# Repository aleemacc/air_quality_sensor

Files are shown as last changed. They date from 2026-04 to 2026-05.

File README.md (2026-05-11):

# Description
This project consists on the full development of an embedded system, with the purpose of measuring air quality.
### Included in this project:
- PCB design and schematics
- Firmware for the device
- Communication with other devices
- Integration with external systems (graphical interface)

# Characteristics
- The device will be able to measure the following:
  - Temperature
  - Humidity
  - CO2 levels
  - TVOC
  - NOx
  - LPG
  - CO
- Wireless connectivity (WiFi, BLE or LoRa)
- Modularity. Ideally you should be able to use only the sensors you need.

# Hardware
## ESP32-C6
The device is built around Seed Studio's ESP32-C6 dev-board, this simplifies the PCB design. Given its size and extensive set of features, it gives the project tons of flexibility.

## Sensors
### SCD41
Sensirion's SCD41 provides temperature, humidity and CO2 measurements with enough precision for home use. It also includes calibration for the CO2 measurements.
### SGP41
Also from Sensirion, but it measures TVOC and NOx. Temperature from the previous sensor can be used to calibrate the SGP41.
### MQ-6
Manufactured by SparkFun, this is a LPG sensor.
### MQ-7
Once again manufactured by SparkFun, this senses Carbon Monoxide.

## Display
The design features a FFC connector to add a TFT display.

## Power
When powered by the ESP's USB-C connector, the ESP board itself provides power to every component.
When a one cell battery pack is used (ie. 18650 or 18300 Li-ion), components powered by 3V3 are still managed by the ESP. However, sensors requiring 5V are powered through a Boost Converter that transforms the batteries voltage to a steady 5V.

## Interfaces
The sensor SCD41 and SGP41 communicate over I2C, both MQ-x sensors use an analog signal and the display will be set up to use 4-wire SPI.

# PCB
The current version of the project features a 2 layer PCB, with the bottom one being a ground plane.
The large space in the middle is there to give space for a 18650 or 18300 battery (depending on which sensors are installed). It also serves to distance the SCD41 sensor from heat sources, such as the MCU or the boost converter.
The SCD41 sensor is excluded from the ground plane and placed within an isolation island, for better accuracy in the temperature measurements

# Firmware
This device is intended to work both with home assistant and independently.
For now only yaml code has been added for testing in home assistant with limited functionality.

# Images

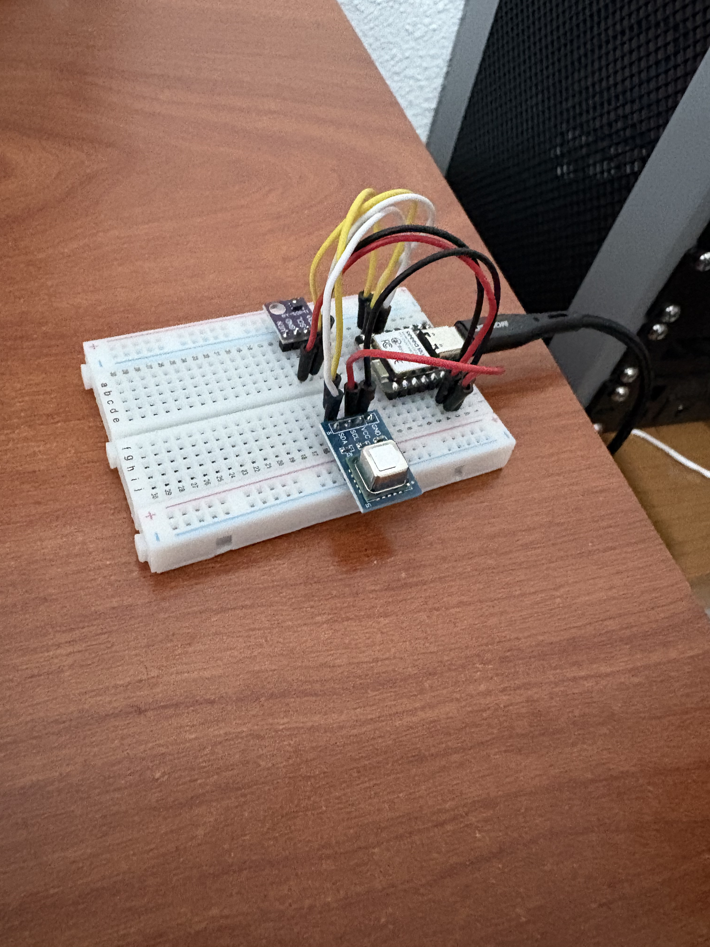
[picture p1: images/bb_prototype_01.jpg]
breadboard prototype
  <br>
This shows the first working prototype on a breadboard, only with the SCD41 and the SGP41 sensors.

# Documentation
All the documentation used for the design of the PCB can be found at `./hardware/kicad/docs/`

# License
This project is licensed under multiple licenses:

- Firmware: Apache License 2.0
- Hardware: CERN Open Hardware Licence v2 - Permissive (OHL-P)

See the LICENSE files in each directory for details.

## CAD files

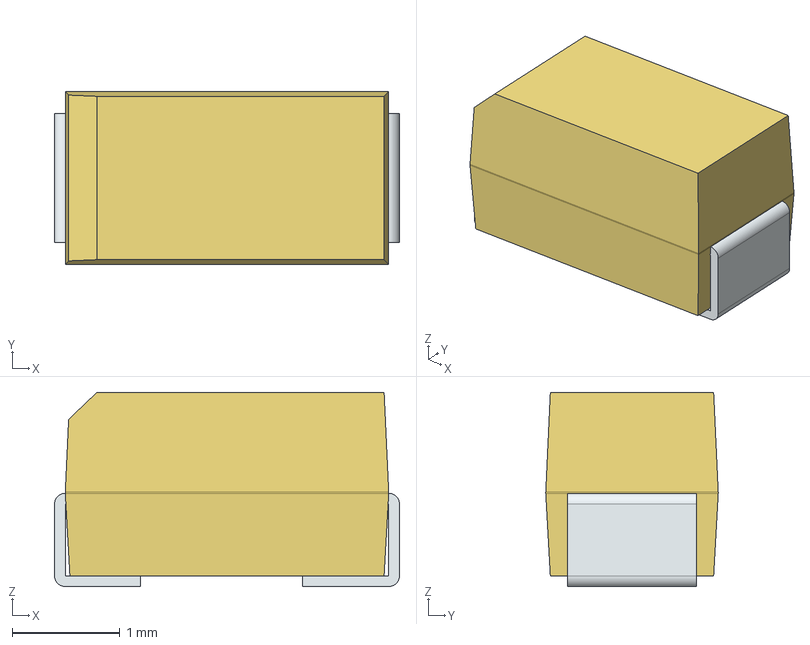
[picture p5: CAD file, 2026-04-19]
hardware/kicad/docs/F930J476MAA/3D/F930J476MAA.stp
3.20 x 1.60 x 1.80 mm
FilletPin1
FilletPin2

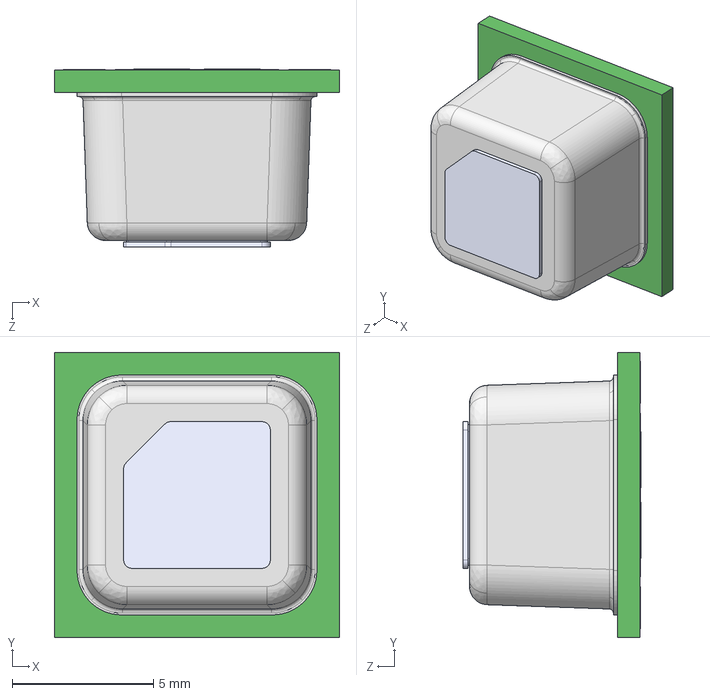
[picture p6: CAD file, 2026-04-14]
hardware/kicad/docs/SCD41-D-R2/3D/SCD41-D-R2.stp
10.1 x 10.1 x 6.31 mm

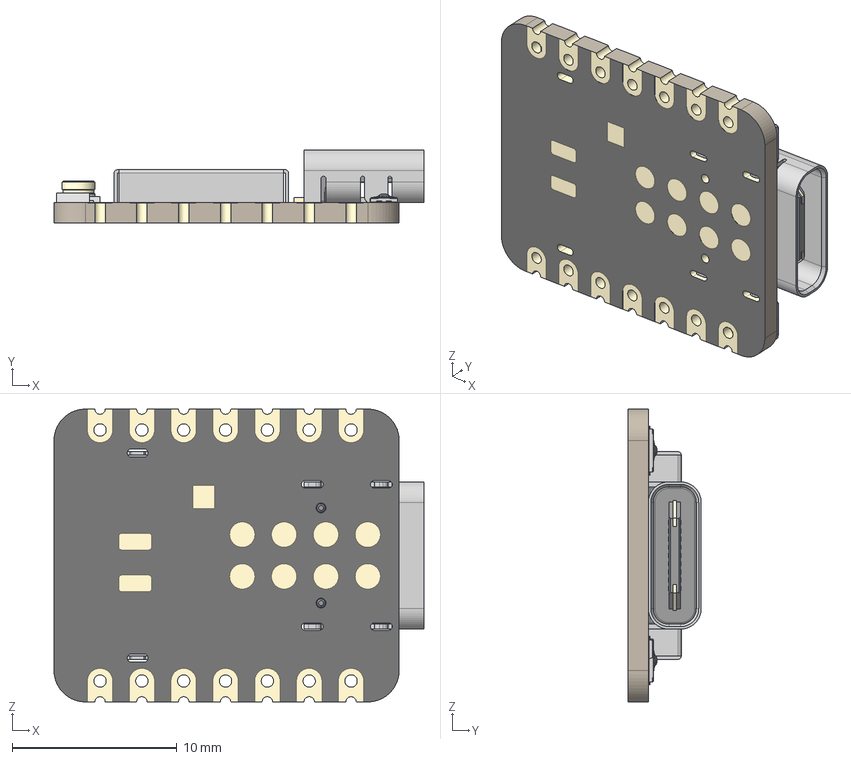
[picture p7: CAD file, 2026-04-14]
hardware/kicad/docs/seed_studio_esp32c6/esp32c6_3d_files/Seeed Studio XIAO ESP32-C6.step
22.5 x 4.46 x 17.8 mm
BOSS-EXTRUDE14_8_
BOSS-EXTRUDE7_4_
BOSS-EXTRUDE7_3_
BOSS-EXTRUDE14_4_
BOSS-EXTRUDE14_2_
BOSS-EXTRUDE14_11_
BOSS-EXTRUDE7_7_
BOSS-EXTRUDE14_9_
BOSS-EXTRUDE14_3_
BOSS-EXTRUDE14_7_
MIRROR2
BOSS-EXTRUDE14_5_
BOSS-EXTRUDE14_12_
BOSS-EXTRUDE7_8_
BOSS-EXTRUDE7_1_
BOSS-EXTRUDE14_10_
BOSS-EXTRUDE7_9_
BOSS-EXTRUDE14_6_
BOSS-EXTRUDE14_1_
BOSS-EXTRUDE7_6_
BOSS-EXTRUDE7_2_
CUT-EXTRUDE5
BOSS-EXTRUDE7_5_
U.FL Connector v1
Shield
SKTAAAE010 x 2
KH5220-A36 (Ceramic Antenna) v2

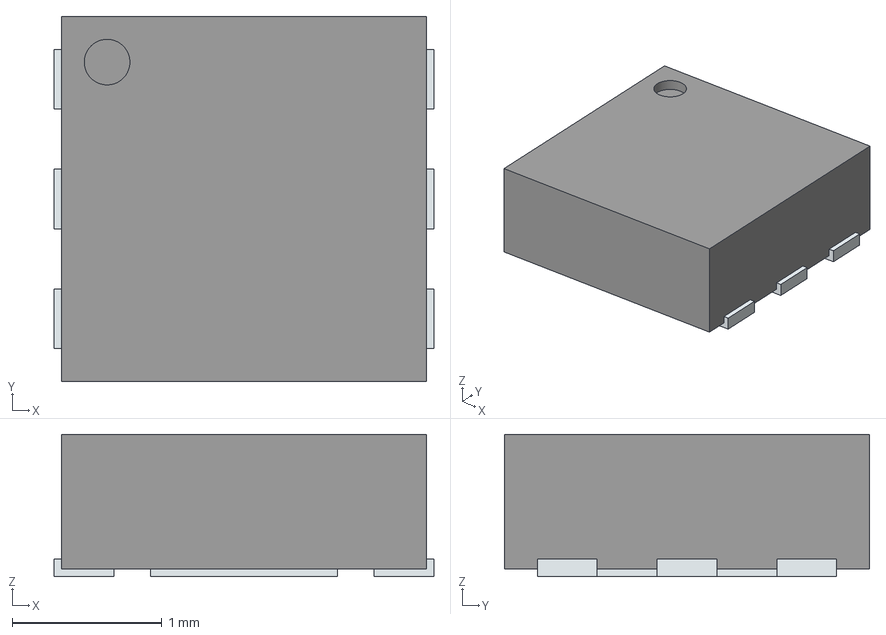
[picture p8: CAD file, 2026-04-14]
hardware/kicad/docs/SGP41-D-R4/3D/SGP41-D-R4.stp
2.54 x 2.44 x 0.95 mm
ThermalPin
PinsArrayLR

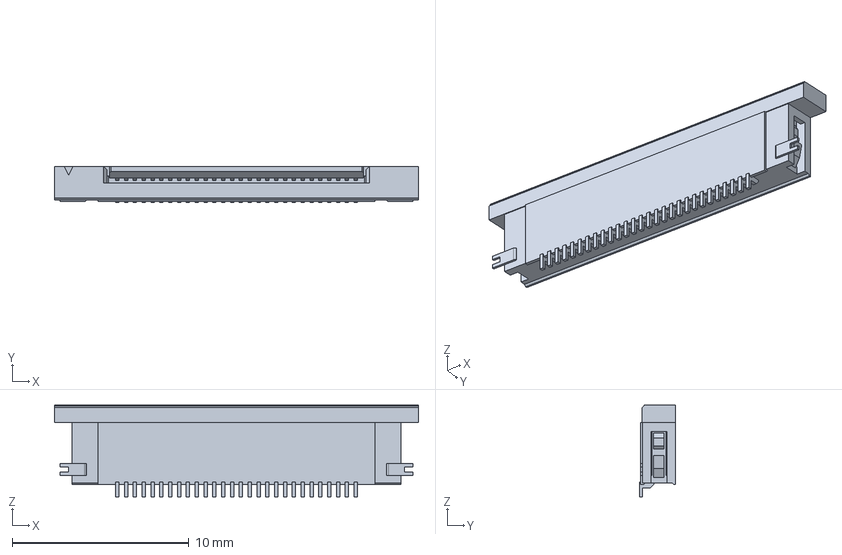
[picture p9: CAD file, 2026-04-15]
hardware/kicad/docs/52435-2871/3D/52435-2871.stp
20.6 x 2.05 x 5.20 mm

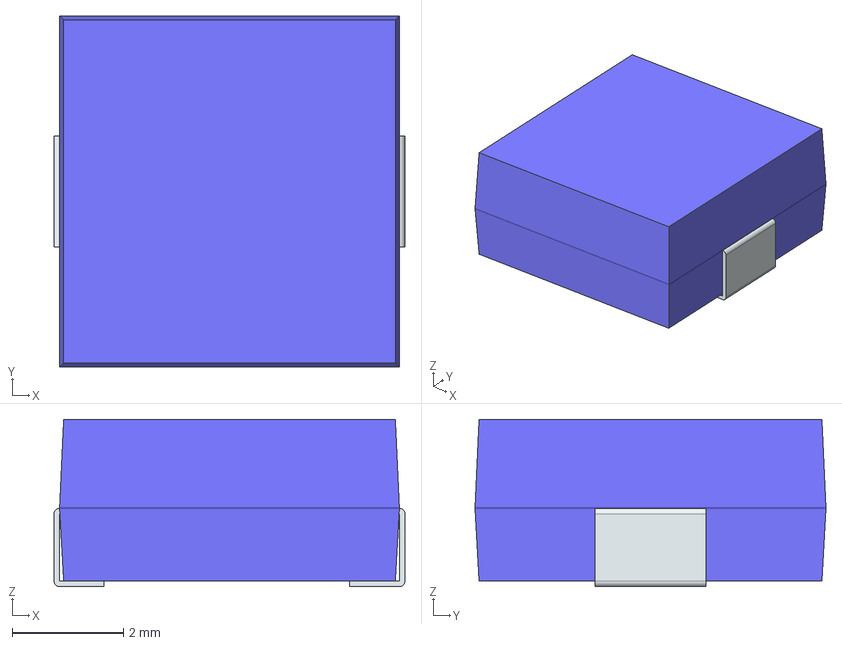
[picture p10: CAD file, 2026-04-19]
hardware/kicad/docs/B82462G4682M/3D/B82462G4682M.stp
6.30 x 6.30 x 3.00 mm
FilletPin1
FilletPin2

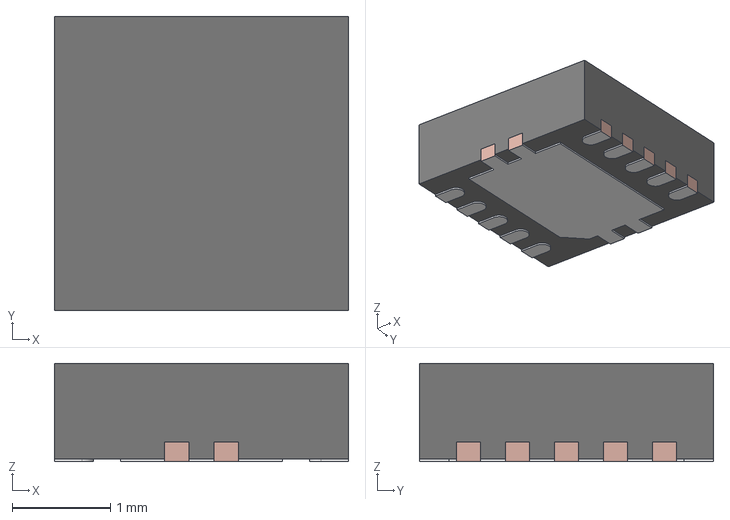
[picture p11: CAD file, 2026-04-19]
hardware/kicad/docs/TPS61027DRCR/3D/TPS61027DRCR.stp
3.00 x 3.00 x 1.00 mm
BODY-SON
FRAME-DRC0010J

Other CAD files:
hardware/kicad/docs/52435-2871/Allegro/524352871.psm
hardware/kicad/docs/52435-2871/DEHDL/52435_2871/chips/chips.prt
hardware/kicad/docs/B82462G4682M/Allegro/indpm6363x300n.psm
hardware/kicad/docs/B82462G4682M/DEHDL/b82462g4682m/chips/chips.prt
hardware/kicad/docs/F930J476MAA/Allegro/cappm3216x180n.psm
hardware/kicad/docs/F930J476MAA/DEHDL/f930j476maa/chips/chips.prt
hardware/kicad/docs/SCD41-D-R2/Allegro/scd41dr2.psm
hardware/kicad/docs/SCD41-D-R2/DEHDL/scd41_d_r2/chips/chips.prt
hardware/kicad/docs/SGP41-D-R4/Allegro/son80p244x244x95-7n.psm
hardware/kicad/docs/SGP41-D-R4/DEHDL/sgp41_d_r4/chips/chips.prt
hardware/kicad/docs/TPS61027DRCR/Allegro/tps74901drcr.psm
hardware/kicad/docs/TPS61027DRCR/DEHDL/tps61027drcr/chips/chips.prt

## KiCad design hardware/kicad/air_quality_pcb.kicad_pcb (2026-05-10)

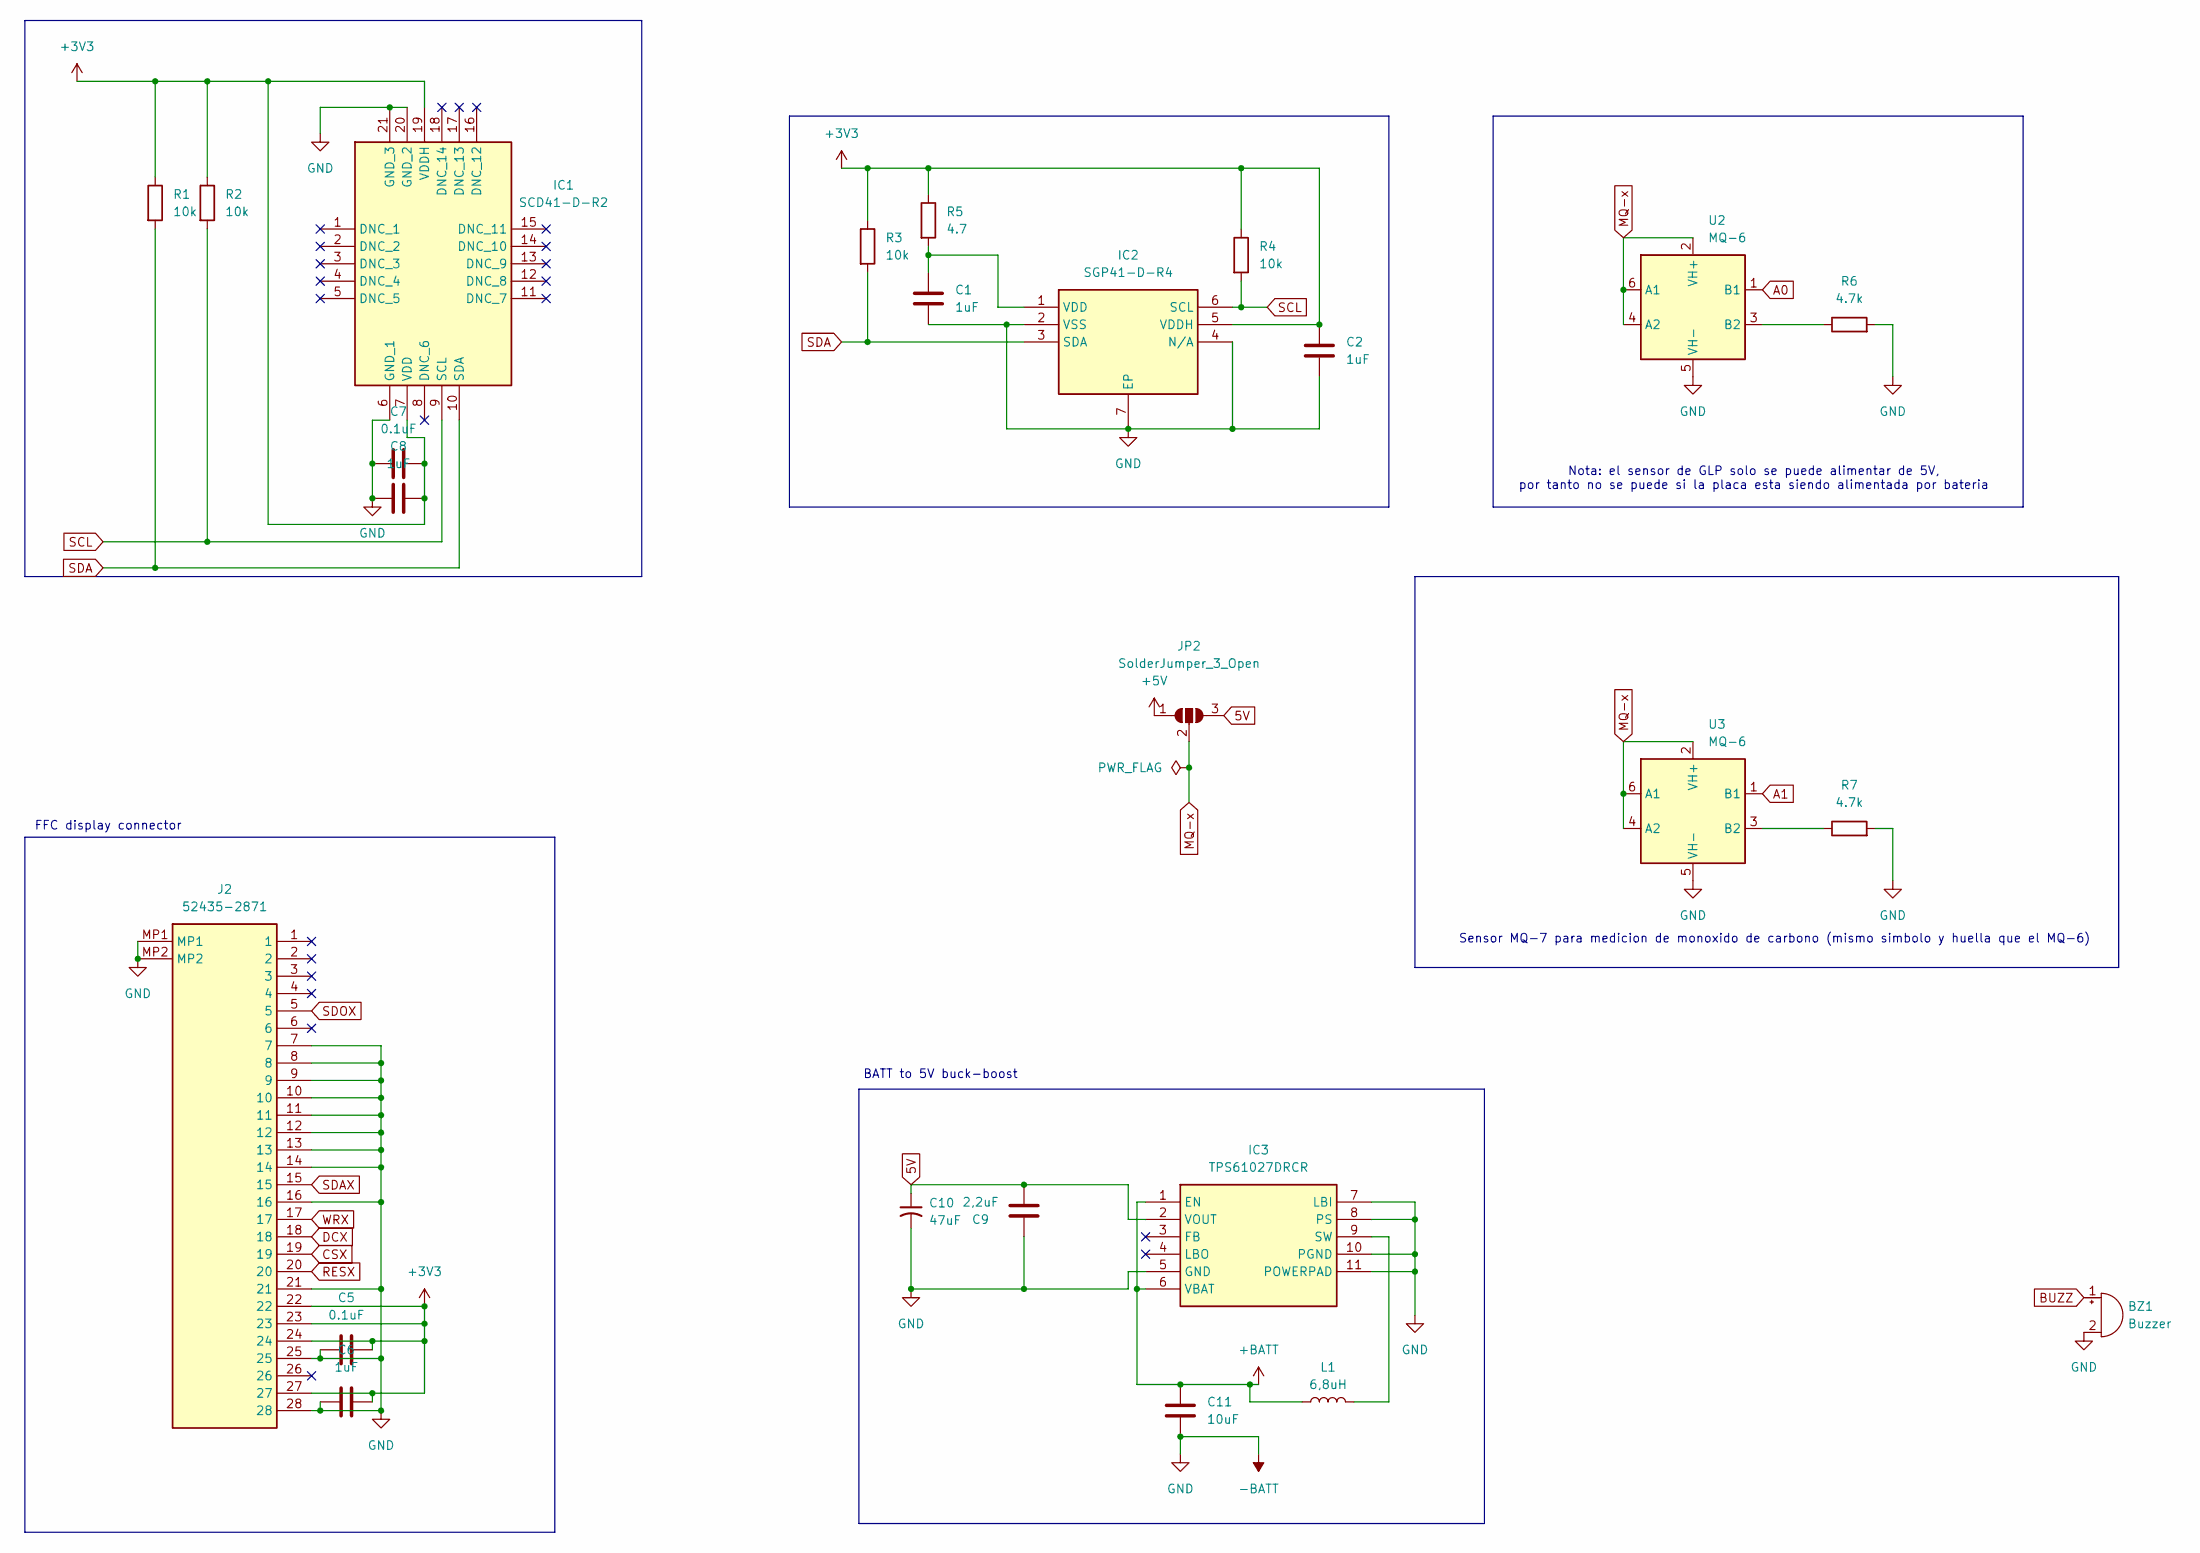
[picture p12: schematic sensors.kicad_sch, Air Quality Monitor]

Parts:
BZ1: Buzzer; Buzzer_12x9.5RM7.6
C1, C2, C6, C8: 1uF; C_1206_3216Metric
C5, C7: 0.1uF; C_1206_3216Metric
C9: 2,2uF; C_1206_3216Metric
C10: 47uF; CAPPM3216X180N
C11: 10uF; C_1206_3216Metric
IC1: SCD41-D-R2; SCD41DR2; Manufacturer_Part_Number SCD41-D-R2; Mouser Part Number 403-SCD41-D-R2
IC2: SGP41-D-R4; SGP41; Manufacturer_Part_Number SGP41-D-R4; Mouser Part Number 403-SGP41-D-R4
IC3: TPS61027DRCR; TPS74901DRCR; Manufacturer_Part_Number TPS61027DRCR; Mouser Part Number 595-TPS61027DRCR
J2: 52435-2871; display_connector; Manufacturer_Part_Number 52435-2871; Mouser Part Number 538-52435-2871
JP2: SolderJumper_3_Open; SolderJumper-3_P1.3mm_Open_RoundedPad1.0x1.5mm_NumberLabels
L1: 6,8uH; INDPM6363X300N
R1, R2, R3, R4: 10k; R_1206_3216Metric
R5: 4.7; R_1206_3216Metric
R6, R7: 4.7k; R_1206_3216Metric
U2, U3: MQ-6

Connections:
5V: C9.1, C10.1, IC3.2 (VOUT), JP2.3 (B)
+3V3: C2.1, C5.1, C6.1, C7.2, C8.2, IC1.7 (VDD), IC1.19 (VDDH), IC2.5 (VDDH), J2.22, J2.23, J2.24, J2.27, R1.1, R2.1, R3.1, R4.1, R5.1; also elsewhere on the board
+5V: JP2.1 (A); also elsewhere on the board
+BATT: C11.2, IC3.1 (EN), IC3.6 (VBAT), L1.1; also elsewhere on the board
-BATT: BZ1.2 (-), C1.2, C2.2, C5.2, C6.2, C7.1, C8.1, C9.2, C10.2, C11.1, IC1.6 (GND_1), IC1.20 (GND_2), IC1.21 (GND_3), IC2.2 (VSS), IC2.4 (N/A), IC2.7 (EP), IC3.5 (GND), IC3.7 (LBI), IC3.8 (PS), IC3.10 (PGND), IC3.11 (POWERPAD), J2.7, J2.8, J2.9, J2.10, J2.11, J2.12, J2.13, J2.14, J2.16, J2.21, J2.25, J2.28, J2.MP1, J2.MP2, R6.2, R7.2, U2.5 (VH-), U3.5 (VH-); also elsewhere on the board
A0: U2.1 (B1); also elsewhere on the board
A1: U3.1 (B1); also elsewhere on the board
BUZZ: BZ1.1 (+); also elsewhere on the board
CSX: J2.19; also elsewhere on the board
DCX: J2.18; also elsewhere on the board
MQ-x: JP2.2 (C), U2.2 (VH+), U2.4 (A2), U2.6 (A1), U3.2 (VH+), U3.4 (A2), U3.6 (A1)
unnamed: C1.1, IC2.1 (VDD), R5.2
unnamed: IC3.9 (SW), L1.2
unnamed: R6.1, U2.3 (B2)
unnamed: R7.1, U3.3 (B2)
RESX: J2.20; also elsewhere on the board
SCL: IC1.9 (SCL), IC2.6 (SCL), R2.2, R4.2; also elsewhere on the board
SDA: IC1.10 (SDA), IC2.3 (SDA), R1.2, R3.2; also elsewhere on the board
SDAX: J2.15; also elsewhere on the board
SDOX: J2.5; also elsewhere on the board
WRX: J2.17; also elsewhere on the board

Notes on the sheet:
Nota: el sensor de GLP solo se puede alimentar de 5V, por tanto no se puede si la placa esta siendo alimentada por bateria
BATT to 5V buck-boost
Sensor MQ-7 para medicion de monoxido de carbono (mismo simbolo y huella que el MQ-6)
FFC display connector

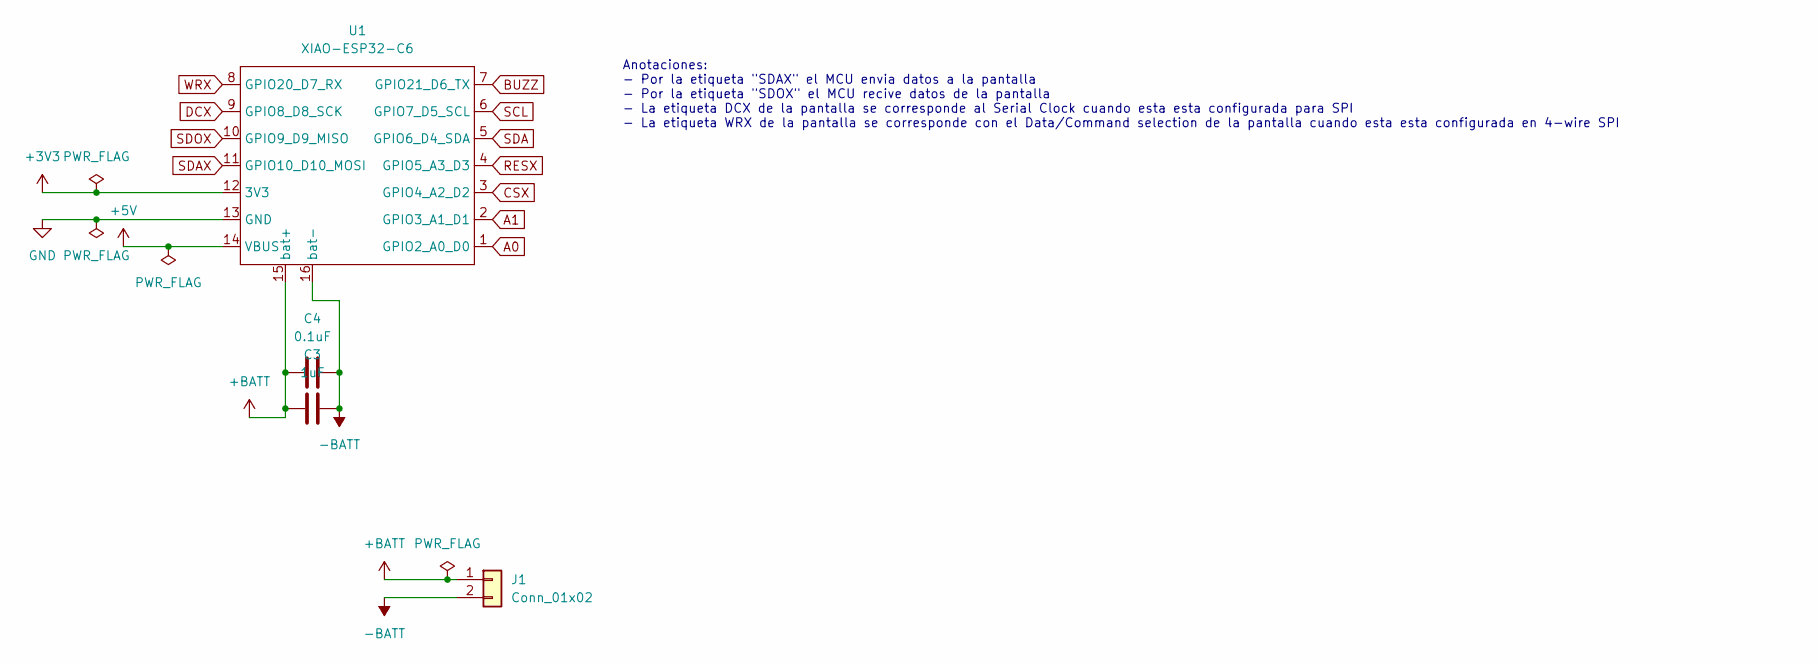
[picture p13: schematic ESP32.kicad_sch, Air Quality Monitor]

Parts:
C3: 1uF; C_1206_3216Metric
C4: 0.1uF; C_1206_3216Metric
J1: Conn_01x02; BATT_connector
U1: XIAO-ESP32-C6; XIAO-ESP32-C6-SMD

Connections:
+3V3: U1.12 (3V3); also elsewhere on the board
+5V: U1.14 (VBUS); also elsewhere on the board
+BATT: C3.1, C4.1, J1.1, U1.15 (bat+); also elsewhere on the board
-BATT: C3.2, C4.2, J1.2, U1.13 (GND), U1.16 (bat-); also elsewhere on the board
A0: U1.1 (GPIO2_A0_D0); also elsewhere on the board
A1: U1.2 (GPIO3_A1_D1); also elsewhere on the board
BUZZ: U1.7 (GPIO21_D6_TX); also elsewhere on the board
CSX: U1.3 (GPIO4_A2_D2); also elsewhere on the board
DCX: U1.9 (GPIO8_D8_SCK); also elsewhere on the board
RESX: U1.4 (GPIO5_A3_D3); also elsewhere on the board
SCL: U1.6 (GPIO7_D5_SCL); also elsewhere on the board
SDA: U1.5 (GPIO6_D4_SDA); also elsewhere on the board
SDAX: U1.11 (GPIO10_D10_MOSI); also elsewhere on the board
SDOX: U1.10 (GPIO9_D9_MISO); also elsewhere on the board
WRX: U1.8 (GPIO20_D7_RX); also elsewhere on the board

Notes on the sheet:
Anotaciones: - Por la etiqueta "SDAX" el MCU envia datos a la pantalla - Por la etiqueta "SDOX" el MCU recive datos de la pantalla - La etiqueta DCX de la pantalla se corresponde al Serial Clock cuando esta esta configurada para SPI - La etiqueta WRX de la pantalla se corresponde con el Data/Comman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

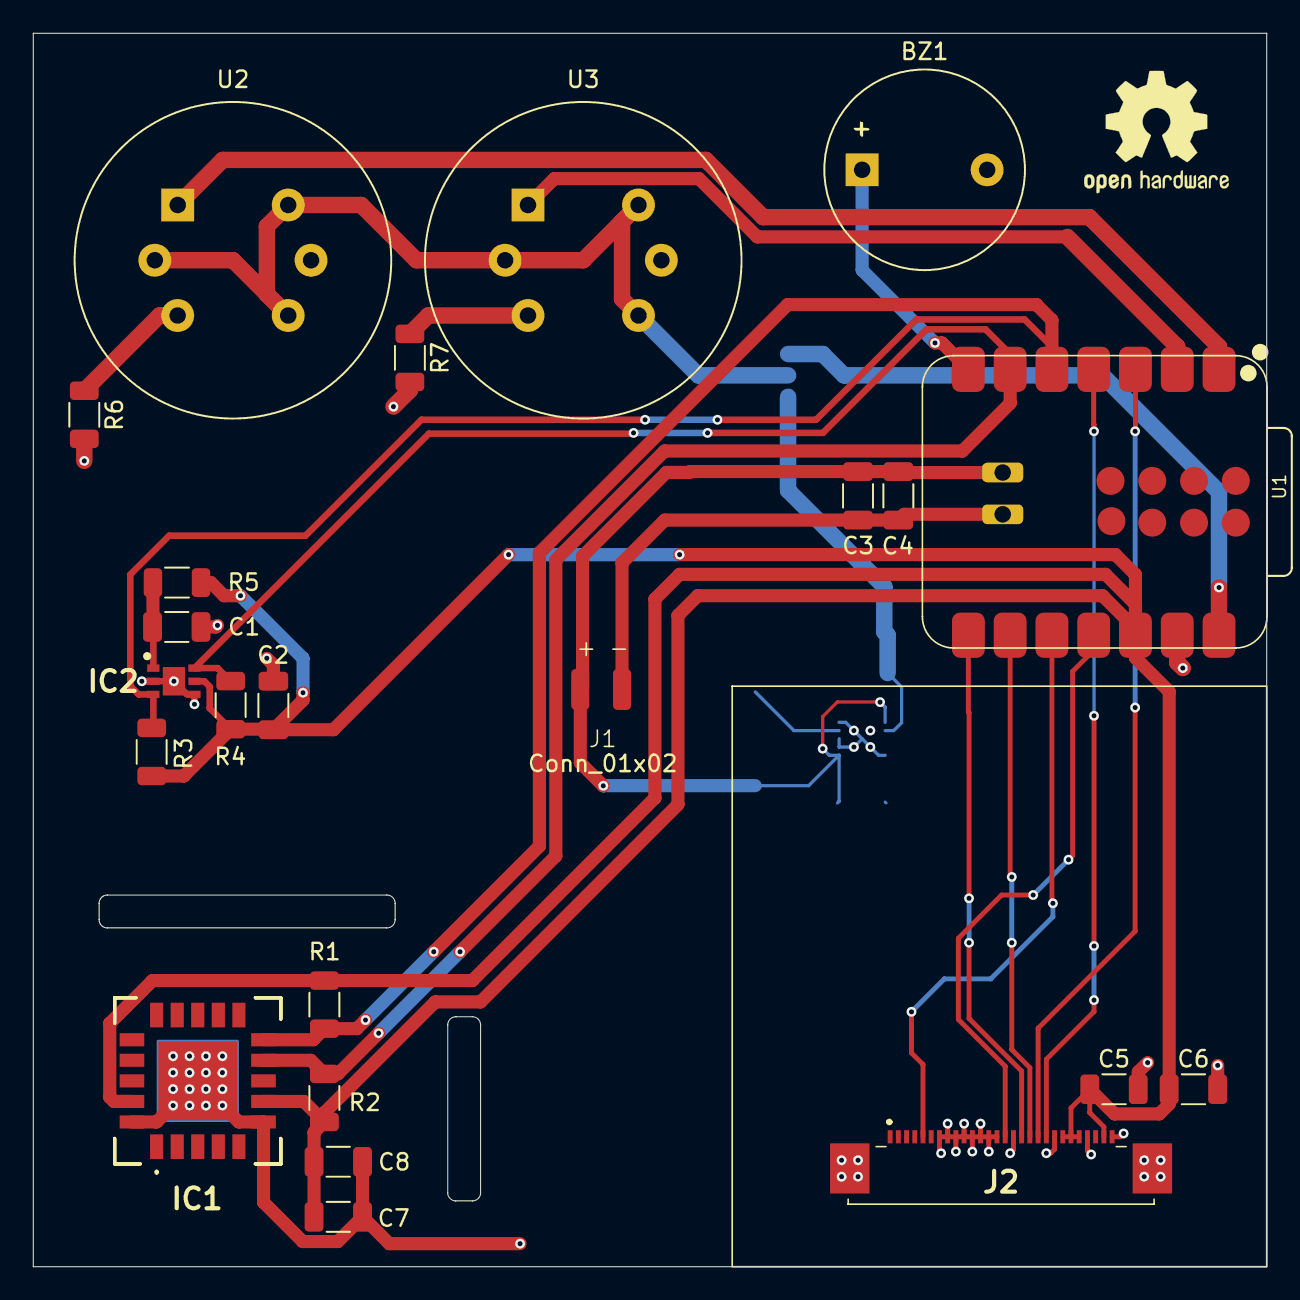
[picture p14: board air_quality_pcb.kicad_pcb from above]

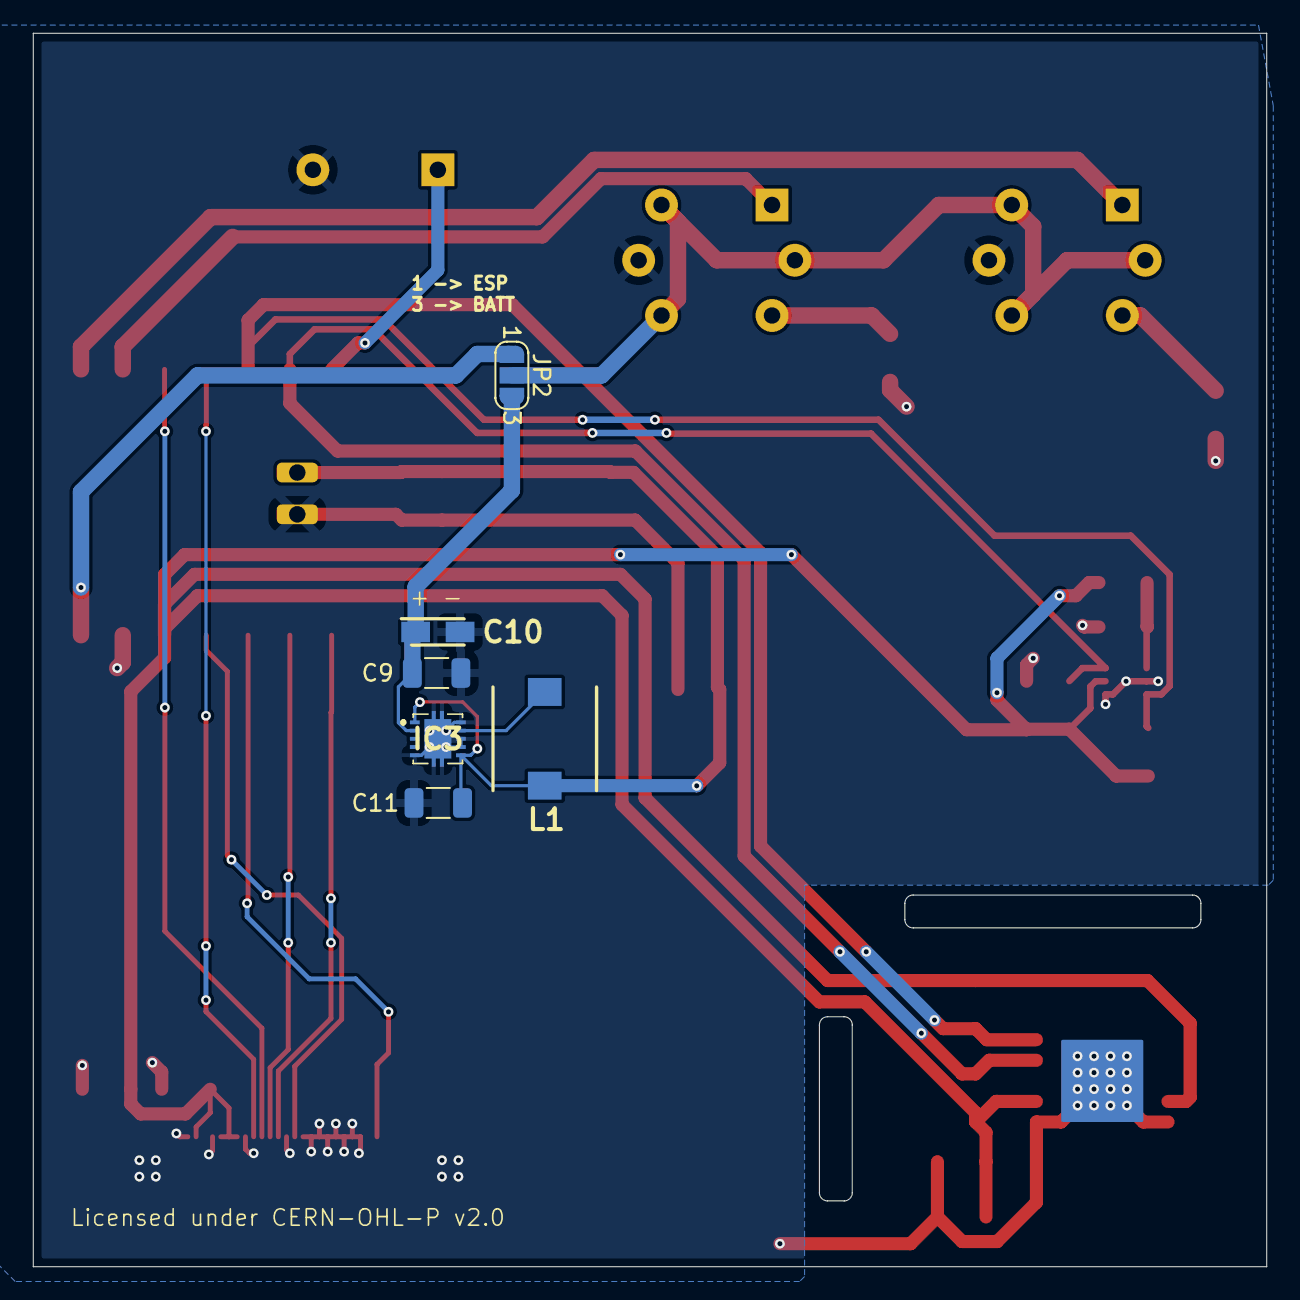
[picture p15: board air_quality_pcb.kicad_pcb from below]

Board: 2 copper layers, 75.0 x 75.0 mm, 29 parts (6 on the bottom side), 21 nets.

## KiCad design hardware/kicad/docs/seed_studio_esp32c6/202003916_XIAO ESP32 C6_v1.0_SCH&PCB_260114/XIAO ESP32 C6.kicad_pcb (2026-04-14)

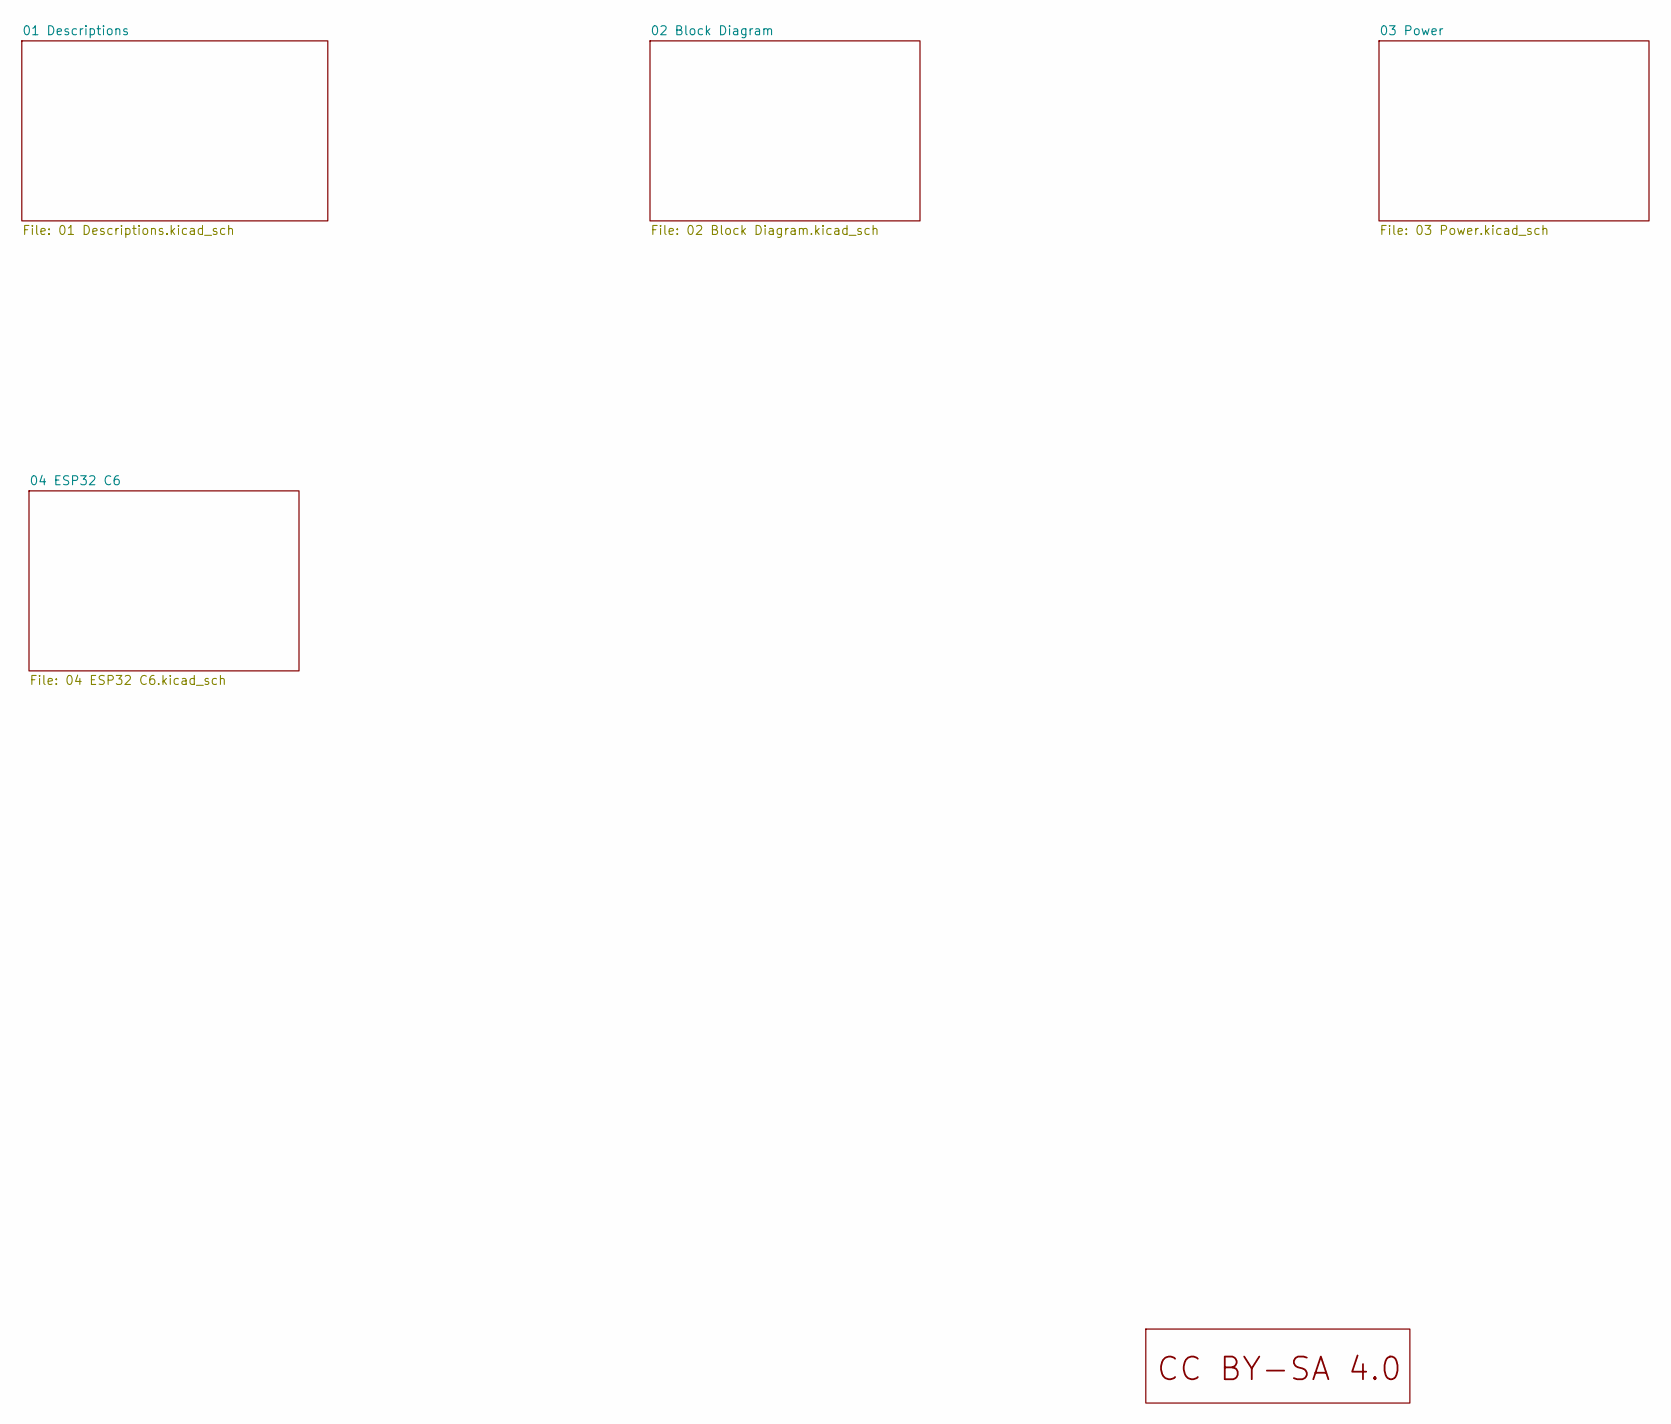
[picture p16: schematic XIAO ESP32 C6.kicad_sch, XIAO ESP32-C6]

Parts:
U6: LOGO_CC_BY-SA_4.0

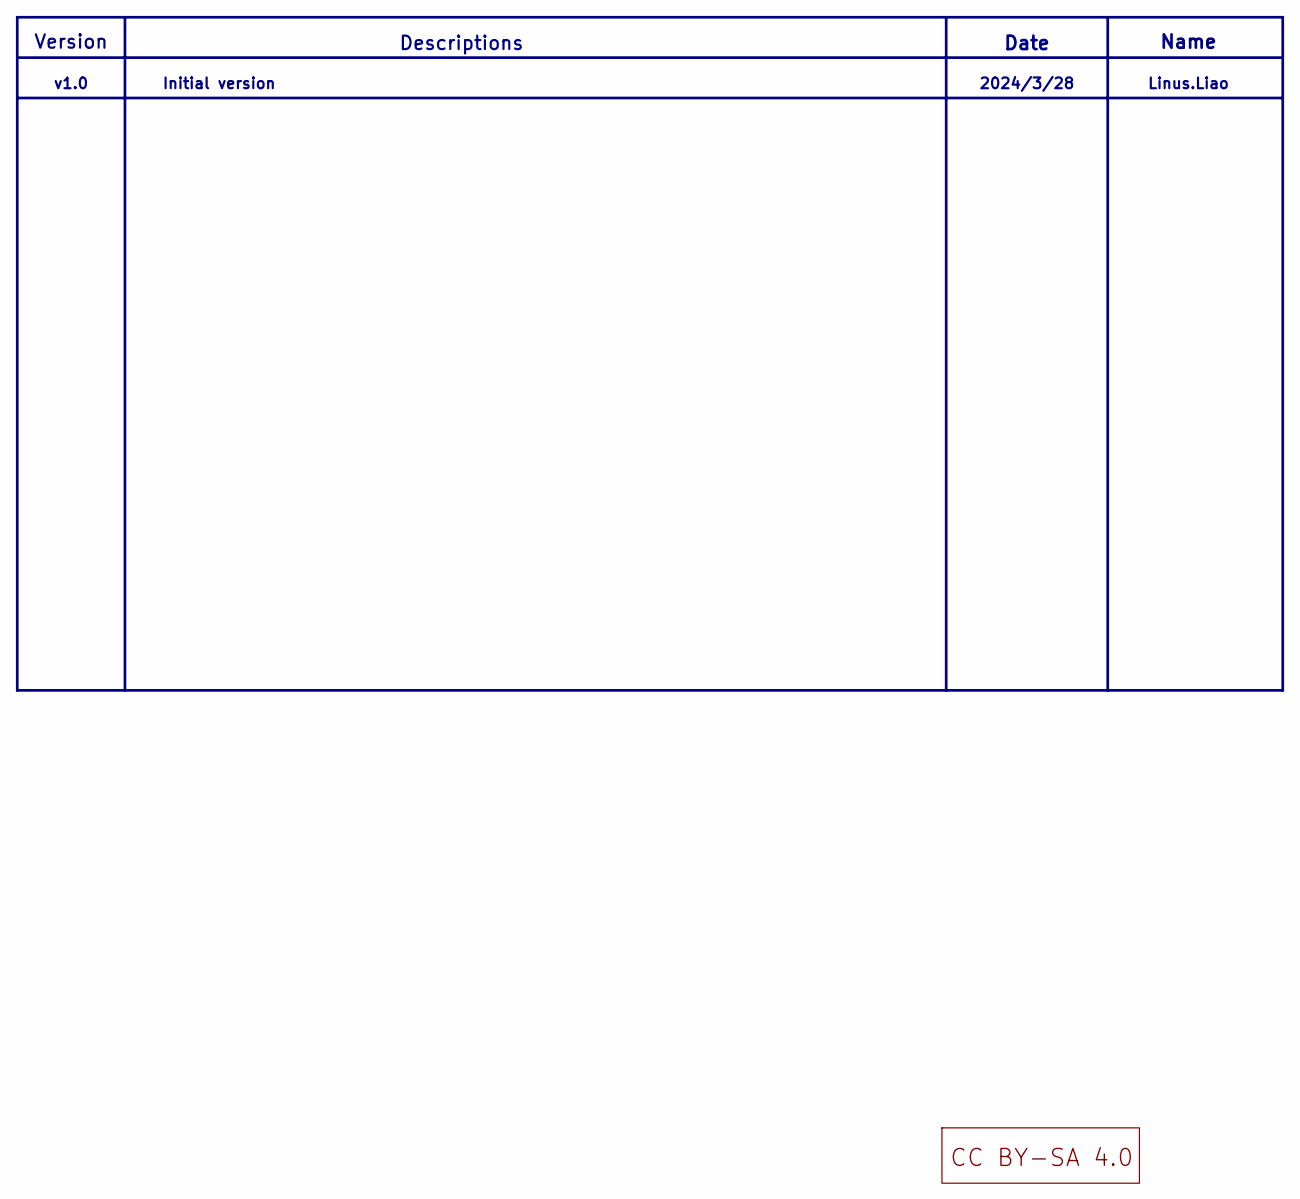
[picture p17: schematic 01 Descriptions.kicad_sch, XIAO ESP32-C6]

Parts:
U7: LOGO_CC_BY-SA_4.0

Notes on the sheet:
Date
Descriptions
Linus.Liao
2024/3/28
v1.0
Initial version
Name
Version

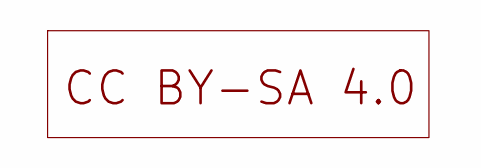
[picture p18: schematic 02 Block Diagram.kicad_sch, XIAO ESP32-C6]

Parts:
U8: LOGO_CC_BY-SA_4.0

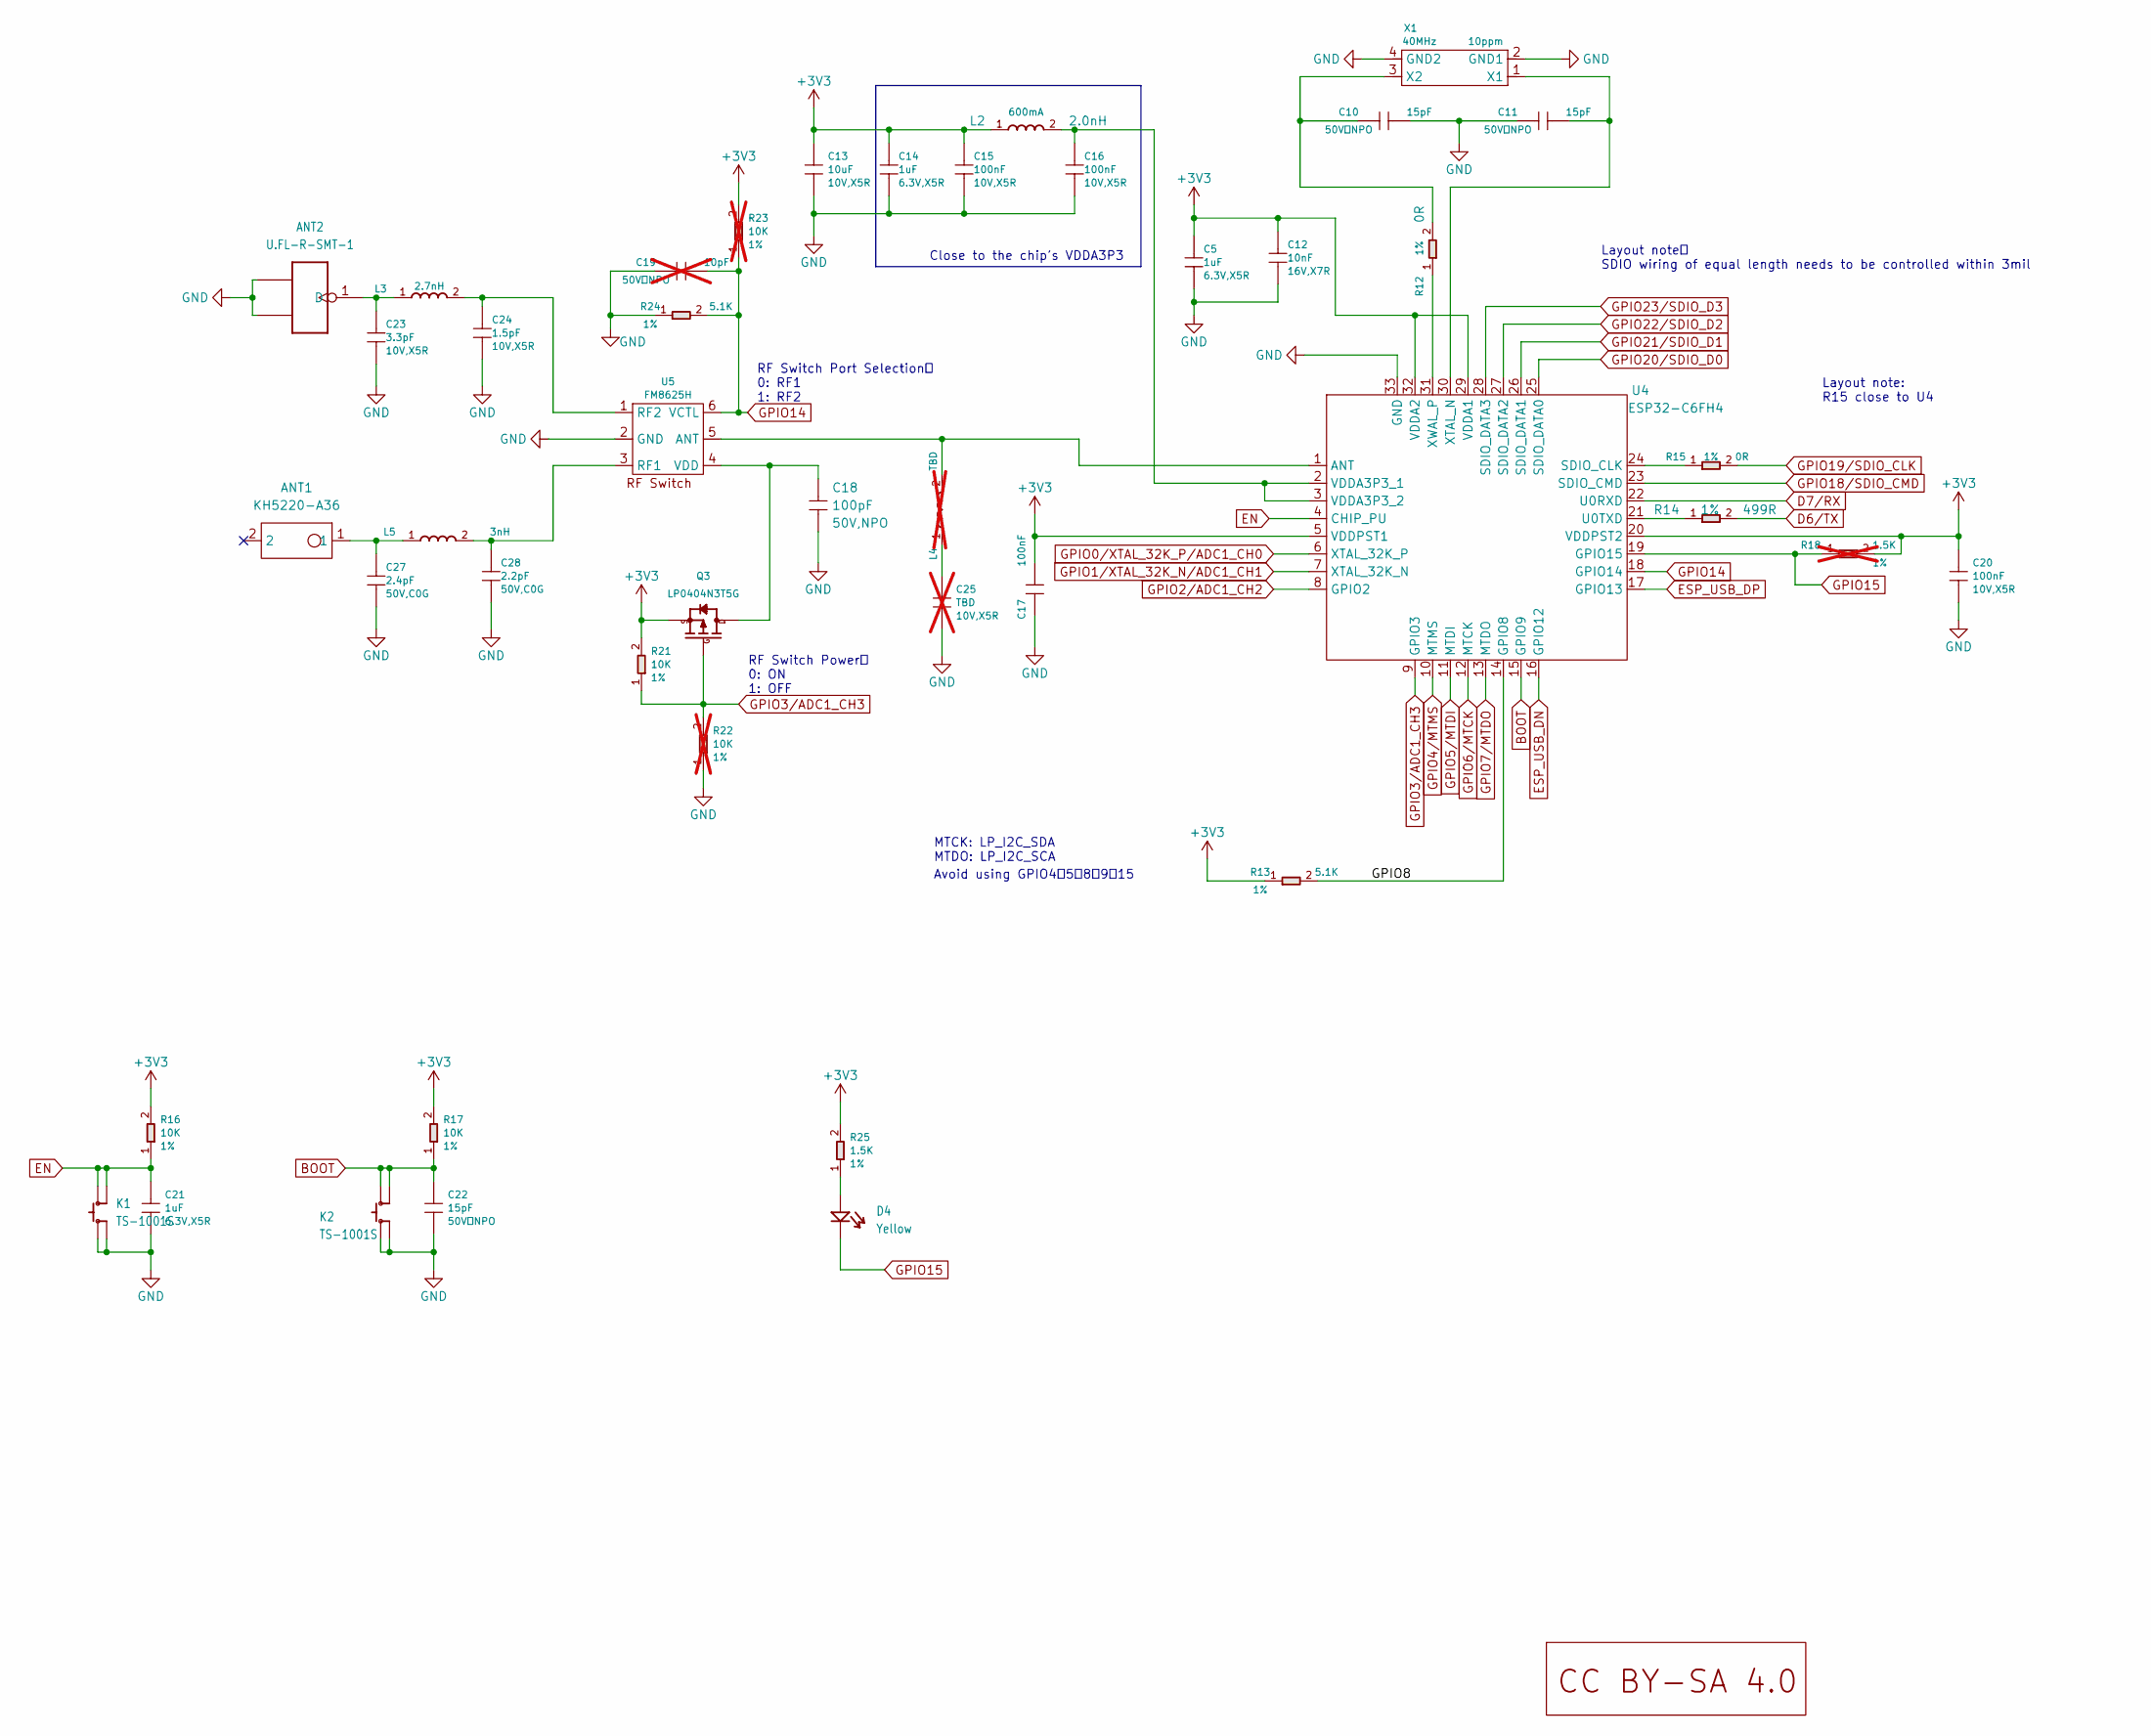
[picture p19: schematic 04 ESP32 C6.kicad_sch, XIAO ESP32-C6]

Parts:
ANT1: KH5220-A36; ANT2P-5.2x2x1.1MM; MPN KH5220-A36
ANT2: U.FL-R-SMT-1; U-FL3P-SMD-2.6X2.6X1.0MM; MPN U.FL-R-SMT-1
C5, C14, C21: 1uF; C0201; Voltage Rating 6.3V,X5R; MPN CC0201MRX5R5BB105
C10, C11, C22: 15pF; C0201; Voltage Rating 50V，NPO; MPN CC0201JRNPO9BN150
C12: 10nF; C0201; Voltage Rating 16V,X7R; MPN CC0201KRX7R7BB103
C13: 10uF; C0402; Voltage Rating 10V,X5R; MPN CC0402MRX5R6BB106
C15, C16, C17, C20: 100nF; C0201; Voltage Rating 10V,X5R; MPN CC0201KRX5R6BB104
C18: 100pF; C0201; Voltage Rating 50V,NPO; MPN CC0201JRNPO9BN101
C19: 10pF; C0201; Voltage Rating 50V，NPO; MPN CC0201JRNPO8BN100; not fitted
C23: 3.3pF; C0201; Voltage Rating 10V,X5R; MPN CQ0201BRNPO8BN3R3
C24: 1.5pF; C0201; Voltage Rating 10V,X5R; MPN CC0201BRNPO9BN1R5
C25: TBD; C0201; Voltage Rating 10V,X5R; Part Type Ceramic; not fitted
C27: 2.4pF; C0201; Voltage Rating 50V,C0G; MPN GRM0335C1H2R4BA01D
C28: 2.2pF; C0201; Voltage Rating 50V,C0G; MPN GRM0335C1H2R2BA01D
D4: Yellow; LED-0402; MPN 16-213/Y2C-AN2Q1B/3T
K1, K2: TS-1001S; SW4-SMD-2.8-2.6X1.6X0.53MM; MPN TS-1001S
L2: 2.0nH; L0201; Rating 600mA; MPN LQP03HQ2N0B02D
L3: 2.7nH; L0201; MPN LQP03TN2N7B02D
L4: TBD; L0201; Part Type L; not fitted
L5: 3nH; L0201; MPN LQP03TN3N0B02D
Q3: LP0404N3T5G; PMOS_1.0X0.6X0.35MM; MPN LP0404N3T5G
R12, R15: 0R; R0201; Power Rating 1%; MPN RC0201FR-070RL
R13, R24: 5.1K; R0201; Power Rating 1%; MPN RC0201FR-075K1L
R14: 499R; R0201; Power Rating 1%; MPN RC0201FR-07499RL
R16, R17, R21: 10K; R0201; Power Rating 1%; MPN RC0201FR-0710KL
R18: 1.5K; R0201; Power Rating 1%; MPN RC0201FR-071K5L; not fitted
R22, R23: 10K; R0201; Power Rating 1%; MPN RC0201FR-0710KL; not fitted
R25: 1.5K; R0201; Power Rating 1%; MPN RC0201FR-071K5L
U4: ESP32-C6FH4; QFN32-0.5-5X5MM; MPN ESP32-C6FH4
U5: FM8625H; DFN6-0.4-1.1X0.7X0.45MM; MPN FM8625H
U10: LOGO_CC_BY-SA_4.0
X1: 40MHz; X4-SMD-1.6X1.2MM; Rating 10ppm; MPN CJ17-400001010B20

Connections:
+3V3: C5.1, C12.1, C13.1, C14.1, C15.1, C17.1, C20.1, L2.1, Q3.2 (S), R13.1, R16.2, R17.2, R18.2, R21.2, R23.2, R25.2, U4.5 (VDDPST1), U4.20 (VDDPST2), U4.29 (VDDA1), U4.32 (VDDA2); also elsewhere on the board
/04 ESP32 C6/GPIO8: R13.2, U4.14 (GPIO8)
BOOT: C22.1, K2.3 (B0), K2.4 (B1), R17.1, U4.15 (GPIO9); also elsewhere on the board
D6/TX: R14.2; also elsewhere on the board
D7/RX: U4.22 (U0RXD); also elsewhere on the board
EN: C21.1, K1.3 (B0), K1.4 (B1), R16.1, U4.4 (CHIP_PU); also elsewhere on the board
ESP_USB_DN: U4.16 (GPIO12); also elsewhere on the board
ESP_USB_DP: U4.17 (GPIO13); also elsewhere on the board
GND: ANT2.2 (GND1), ANT2.3 (GND2), C5.2, C10.2, C11.1, C12.2, C13.2, C14.2, C15.2, C16.2, C17.2, C18.2, C19.1, C20.2, C21.2, C22.2, C23.2, C24.2, C25.2, C27.2, C28.2, K1.1 (A0), K1.2 (A1), K2.1 (A0), K2.2 (A1), R22.1, R24.1, U4.33 (GND), U5.2 (GND), X1.2 (GND1), X1.4 (GND2); also elsewhere on the board
GPIO0/XTAL_32K_P/ADC1_CH0: U4.6 (XTAL_32K_P); also elsewhere on the board
GPIO1/XTAL_32K_N/ADC1_CH1: U4.7 (XTAL_32K_N); also elsewhere on the board
GPIO2/ADC1_CH2: U4.8 (GPIO2); also elsewhere on the board
GPIO3/ADC1_CH3: Q3.1 (G), R21.1, R22.2, U4.9 (GPIO3)
GPIO4/MTMS: U4.10 (MTMS); also elsewhere on the board
GPIO5/MTDI: U4.11 (MTDI); also elsewhere on the board
GPIO6/MTCK: U4.12 (MTCK); also elsewhere on the board
GPIO7/MTDO: U4.13 (MTDO); also elsewhere on the board
GPIO14: C19.2, R23.1, R24.2, U4.18 (GPIO14), U5.6 (VCTL)
GPIO15: D4.2 (-), R18.1, U4.19 (GPIO15)
GPIO18/SDIO_CMD: U4.23 (SDIO_CMD); also elsewhere on the board
GPIO19/SDIO_CLK: R15.2; also elsewhere on the board
GPIO20/SDIO_D0: U4.25 (SDIO_DATA0); also elsewhere on the board
GPIO21/SDIO_D1: U4.26 (SDIO_DATA1); also elsewhere on the board
GPIO22/SDIO_D2: U4.27 (SDIO_DATA2); also elsewhere on the board
GPIO23/SDIO_D3: U4.28 (SDIO_DATA3); also elsewhere on the board
unnamed: ANT1.1, C27.1, L5.1
unnamed: ANT2.1 (D), C23.1, L3.1
unnamed: C25.1, L4.1
unnamed: D4.1 (+), R25.1
unnamed: C18.1, Q3.3 (D), U5.4 (VDD)
unnamed: L4.2, U4.1 (ANT), U5.5 (ANT)
unnamed: R15.1, U4.24 (SDIO_CLK)
unnamed: R14.1, U4.21 (U0TXD)
unnamed: C16.1, L2.2, U4.2 (VDDA3P3_1), U4.3 (VDDA3P3_2)
unnamed: C11.2, U4.30 (XTAL_N), X1.1 (X1)
unnamed: R12.1, U4.31 (XWAL_P)
unnamed: C28.1, L5.2, U5.3 (RF1)
unnamed: C24.1, L3.2, U5.1 (RF2)
unnamed: C10.1, R12.2, X1.3 (X2)

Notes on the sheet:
Avoid using GPIO4、5、8、9、15
RF Switch Power： 0: ON 1: OFF
Layout note: R15 close to U4
Close to the chip's VDDA3P3
Layout note： SDIO wiring of equal length needs to be controlled within 3mil
RF Switch Port Selection： 0: RF1 1: RF2
MTCK: LP_I2C_SDA MTDO: LP_I2C_SCA

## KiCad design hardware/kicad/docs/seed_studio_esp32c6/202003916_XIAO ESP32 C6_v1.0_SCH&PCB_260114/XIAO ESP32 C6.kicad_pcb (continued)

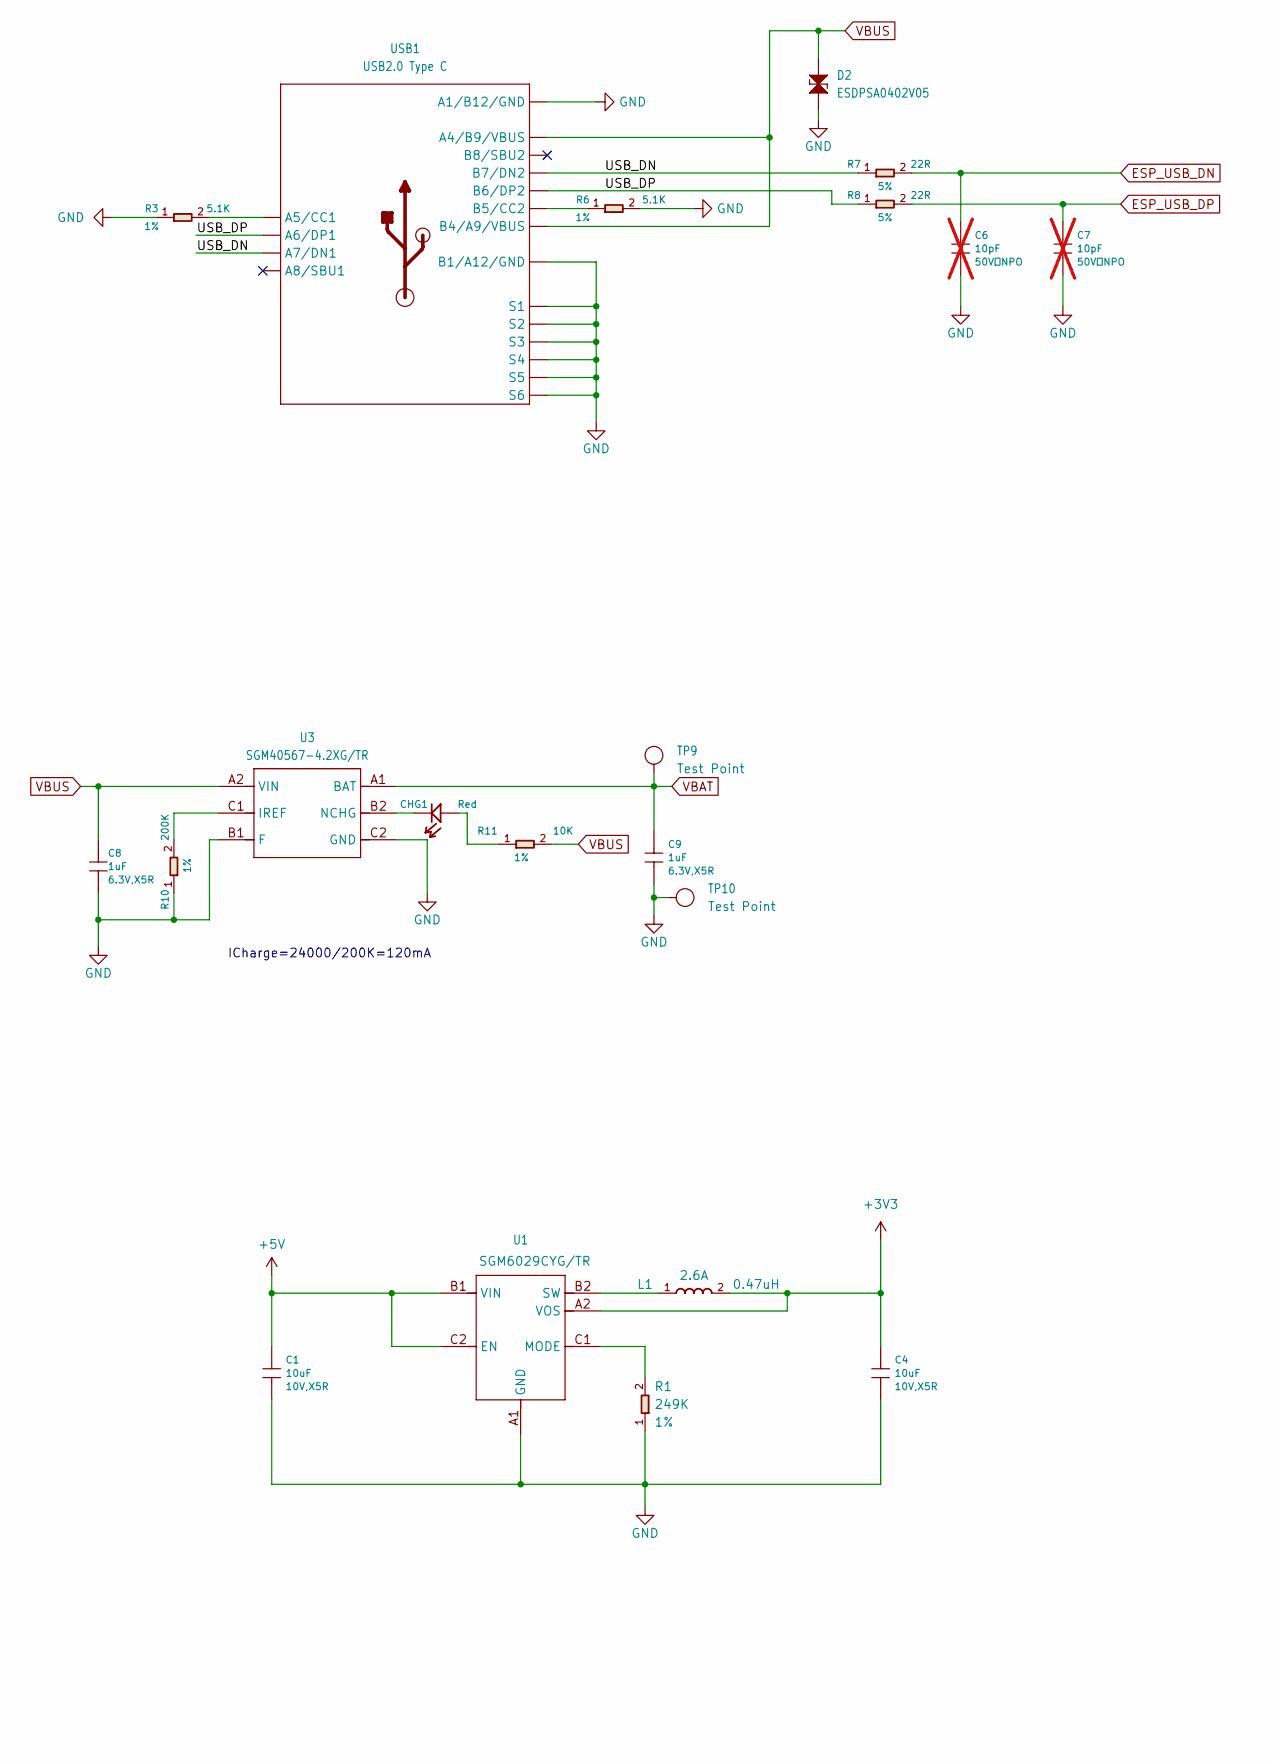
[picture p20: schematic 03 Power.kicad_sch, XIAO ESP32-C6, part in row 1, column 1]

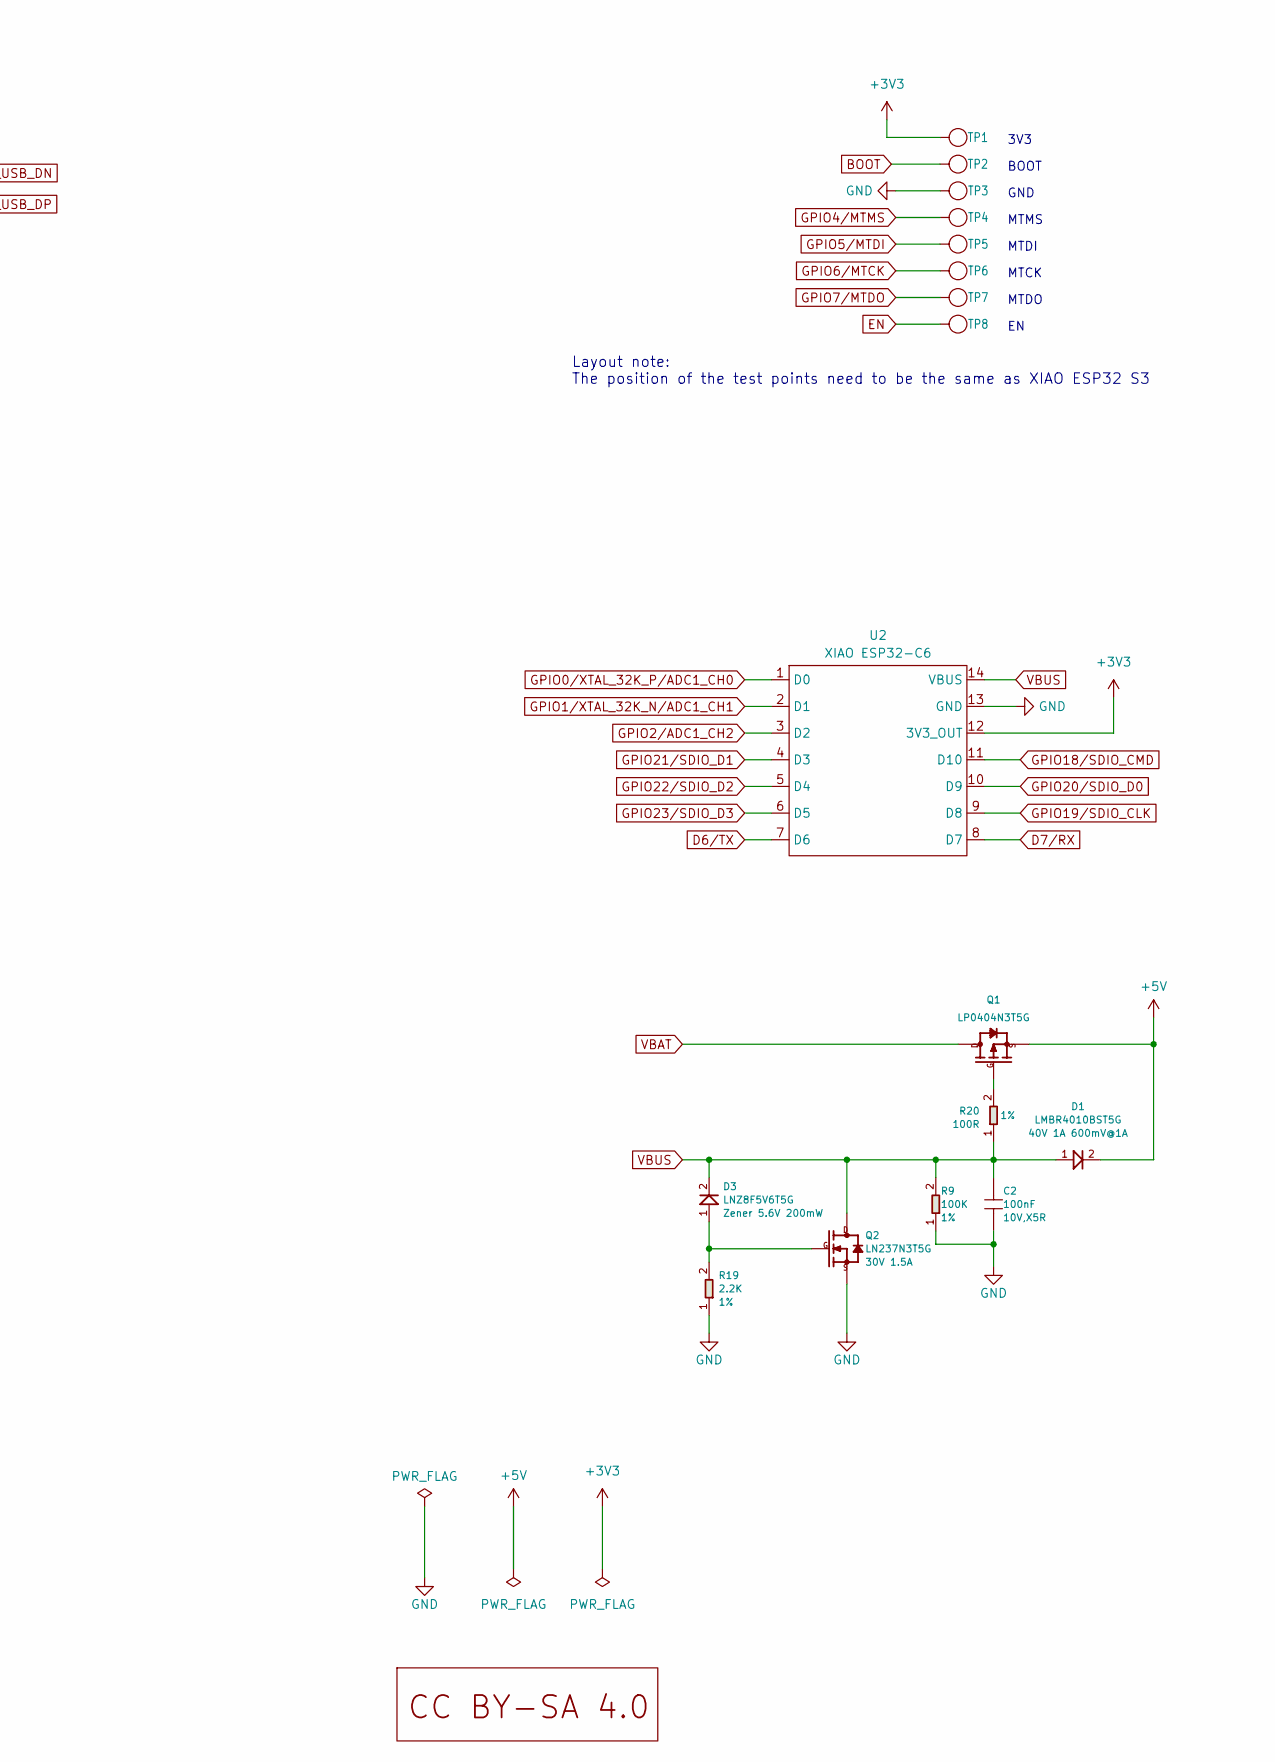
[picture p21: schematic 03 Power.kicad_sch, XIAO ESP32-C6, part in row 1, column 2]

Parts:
C1, C4: 10uF; C0402; Voltage Rating 10V,X5R; MPN CC0402MRX5R6BB106
C2: 100nF; C0201; Voltage Rating 10V,X5R; MPN CC0201KRX5R6BB104
C6, C7: 10pF; C0201; Voltage Rating 50V，NPO; MPN CC0201JRNPO8BN100; not fitted
C8, C9: 1uF; C0201; Voltage Rating 6.3V,X5R; MPN CC0201MRX5R5BB105
CHG1: Red; LED-0402; MPN BL-HUB37A-AV-TRB
D1: LMBR4010BST5G; DFN1006-2L; Rating 40V 1A 600mV@1A; MPN LMBR4010BST5G
D2: ESDPSA0402V05; ESD-0402; MPN ESDPSA0402V05
D3: LNZ8F5V6T5G; DFN1006-2L; Rating Zener 5.6V 200mW; MPN LNZ8F5V6T5G
L1: 0.47uH; L0603; Rating 2.6A; MPN TFM160808ALC-R47MTAA
Q1: LP0404N3T5G; PMOS_1.0X0.6X0.35MM; MPN LP0404N3T5G
Q2: LN237N3T5G; PMOS_1.0X0.6X0.35MM; Rating 30V 1.5A; MPN LN237N3T5G
R1: 249K; R0201; Power Rating 1%; MPN RC0201FR-07249KL
R3, R6: 5.1K; R0201; Power Rating 1%; MPN RC0201FR-075K1L
R7, R8: 22R; R0201; Power Rating 5%; MPN RC0201JR-0722RL
R9: 100K; R0201; Power Rating 1%; MPN RC0201FR-07100KL
R10: 200K; R0201; Power Rating 1%; MPN RC0201FR-07200KL
R11: 10K; R0201; Power Rating 1%; MPN RC0201FR-0710KL
R19: 2.2K; R0201; Power Rating 1%; MPN RC0201FR-072K2L
R20: 100R; R0201; Power Rating 1%; MPN RC0201FR-07100RL
TP1, TP2, TP3, TP4, TP5, TP6, TP7, TP8: Test Point; TP-D45MIL; Part Type Test Point
TP9, TP10: Test Point; TP-80X40MIL; Part Type Test Point
U1: SMD IC PMIC;DCDC Buck-ADJ-1A,Vin 1.95V to 5.5V,Vo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; BGA6-0.35-0.745X10.95X0.4MM; MPN SGM6029CYG/TR
U2: XIAO ESP32-C6; XIAO-Add-On
U3: SGM40567-4.2XG/TR; WLCSP-0.4-0.92X1.16X0.4MM; MPN SGM40567-4.2XG/TR
U9: LOGO_CC_BY-SA_4.0
USB1: USB2.0 Type C; USB2.0-TYPE-C; MPN UBF31-0171

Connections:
+3V3: C4.1, L1.2, TP1.1 (T), U1.A2 (VOS), U2.12 (3V3); also elsewhere on the board
+5V: C1.1, D1.2, Q1.2 (S), U1.B1 (VIN), U1.C2 (EN)
/03 Power/USB_DN: R7.1, USB1.A7 (A7/DN1), USB1.B7 (B7/DN2)
/03 Power/USB_DP: R8.1, USB1.A6 (A6/DP1), USB1.B6 (B6/DP2)
BOOT: TP2.1 (T); also elsewhere on the board
D6/TX: U2.7 (PB08_A6_D6_TX); also elsewhere on the board
D7/RX: U2.8 (PB09_A7_D7_RX); also elsewhere on the board
EN: TP8.1 (T); also elsewhere on the board
ESP_USB_DN: C6.1, R7.2; also elsewhere on the board
ESP_USB_DP: C7.1, R8.2; also elsewhere on the board
GND: C1.2, C2.2, C4.2, C6.2, C7.2, C8.2, C9.2, D2.1, Q2.2 (S), R1.1, R3.1, R6.2, R9.1, R10.1, R19.1, TP3.1 (T), TP10.1 (T), U1.A1 (GND), U2.13 (GND), U3.B1 (F), U3.C2 (GND), USB1.A1_B12 (A1/B12/GND), USB1.B1_A12 (B1/A12/GND), USB1.S1, USB1.S2, USB1.S3, USB1.S4, USB1.S5, USB1.S6; also elsewhere on the board
GPIO0/XTAL_32K_P/ADC1_CH0: U2.1 (PA02_A0_D0); also elsewhere on the board
GPIO1/XTAL_32K_N/ADC1_CH1: U2.2 (PA4_A1_D1); also elsewhere on the board
GPIO2/ADC1_CH2: U2.3 (PA10_A2_D2); also elsewhere on the board
GPIO4/MTMS: TP4.1 (T); also elsewhere on the board
GPIO5/MTDI: TP5.1 (T); also elsewhere on the board
GPIO6/MTCK: TP6.1 (T); also elsewhere on the board
GPIO7/MTDO: TP7.1 (T); also elsewhere on the board
GPIO18/SDIO_CMD: U2.11 (PA6_A10_D10_MOSI); also elsewhere on the board
GPIO19/SDIO_CLK: U2.9 (PA7_A8_D8_SCK); also elsewhere on the board
GPIO20/SDIO_D0: U2.10 (PA5_A9_D9_MISO); also elsewhere on the board
GPIO21/SDIO_D1: U2.4 (PA11_A3_D3); also elsewhere on the board
GPIO22/SDIO_D2: U2.5 (PA8_A4_D4_SDA); also elsewhere on the board
GPIO23/SDIO_D3: U2.6 (PA9_A5_D5_SCL); also elsewhere on the board
unnamed: CHG1.1 (+), R11.1
unnamed: CHG1.2 (-), U3.B2 (NCHG)
unnamed: Q1.1 (G), R20.2
unnamed: D3.1, Q2.1 (G), R19.2
unnamed: R1.2, U1.C1 (MODE)
unnamed: L1.1, U1.B2 (SW)
unnamed: R10.2, U3.C1 (IREF)
unnamed: R3.2, USB1.A5 (A5/CC1)
unnamed: R6.1, USB1.B5 (B5/CC2)
VBAT: C9.1, Q1.3 (D), TP9.1 (T), U3.A1 (BAT)
VBUS: C2.1, C8.1, D1.1, D2.2, D3.2, Q2.3 (D), R9.2, R11.2, R20.1, U2.14 (5V), U3.A2 (VIN), USB1.A4_B9 (A4/B9/VBUS), USB1.B4_A9 (B4/A9/VBUS)

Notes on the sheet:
MTMS
MTDI
ICharge=24000/200K=120mA
GND
MTDO
Layout note: The position of the test points need to be the same as XIAO ESP32 S3
MTCK
BOOT
3V3

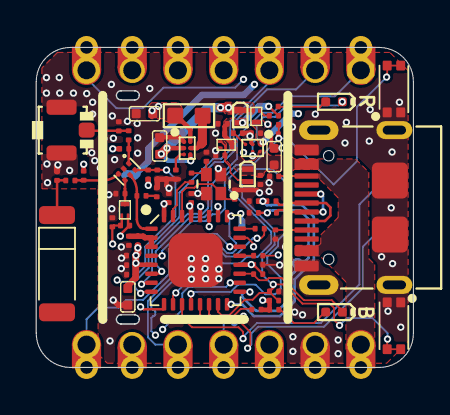
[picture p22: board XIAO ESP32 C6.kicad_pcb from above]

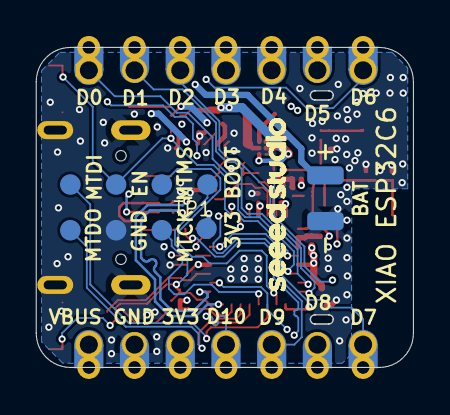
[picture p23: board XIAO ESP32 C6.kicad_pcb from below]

Board: 4 copper layers, 21.0 x 17.8 mm, 82 parts (10 on the bottom side), 53 nets.

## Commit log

2026-04-15 added sensors and display example
    [ESP32.kicad_sch, air_quality_pcb.kicad_pcb, sensors.kicad_sch]
2026-04-15 added mq7 sensor and display connector
    [52435-2871.SchLib, 52435-2871.stp, 524352871.PcbLib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]
2026-04-15 finished routing and added more decoupling caps
    [ESP32.kicad_sch, air_quality_pcb.kicad_pcb, sensors.kicad_sch]
2026-04-19 added buck boost for 5v battery powered
    [B82462G4682M.SchLib, B82462G4682M.stp, CAPPM3216X180N.PcbLib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]
2026-04-20 added buzzer
    [ESP32.kicad_sch, air_quality_pcb.kicad_pcb, sensors.kicad_sch]
2026-04-28 fixed buzzer and MQ-x sensors placement
    [air_quality_pcb.kicad_pcb]
2026-04-28 fixed silkscreen
    [air_quality_pcb.kicad_pcb]
2026-05-10 refactor: changed hardware folder name
    [01 Descriptions.kicad_sch, 02 Block Diagram.kicad_sch, 03 Power.kicad_sch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]
2026-05-10 chore: added licensing
    [01 Descriptions.kicad_sch, 02 Block Diagram.kicad_sch, 03 Power.kicad_sch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]

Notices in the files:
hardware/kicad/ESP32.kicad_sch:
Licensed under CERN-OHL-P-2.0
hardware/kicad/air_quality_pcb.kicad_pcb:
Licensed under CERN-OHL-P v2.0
